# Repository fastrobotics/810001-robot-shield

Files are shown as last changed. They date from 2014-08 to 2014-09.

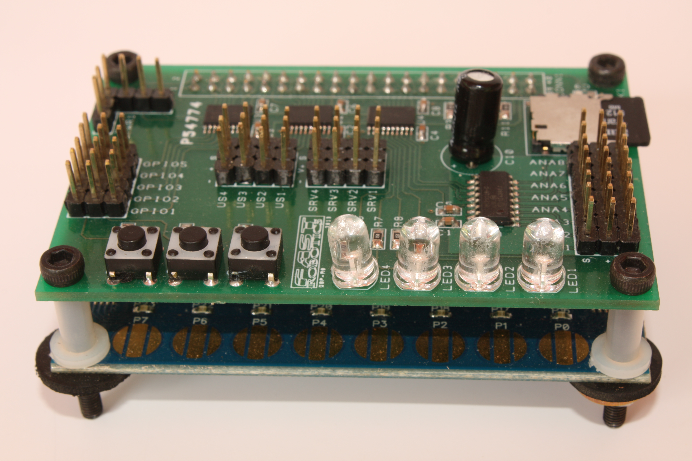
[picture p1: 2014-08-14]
MEDIA/810001A_Robot Shield ISO.JPG

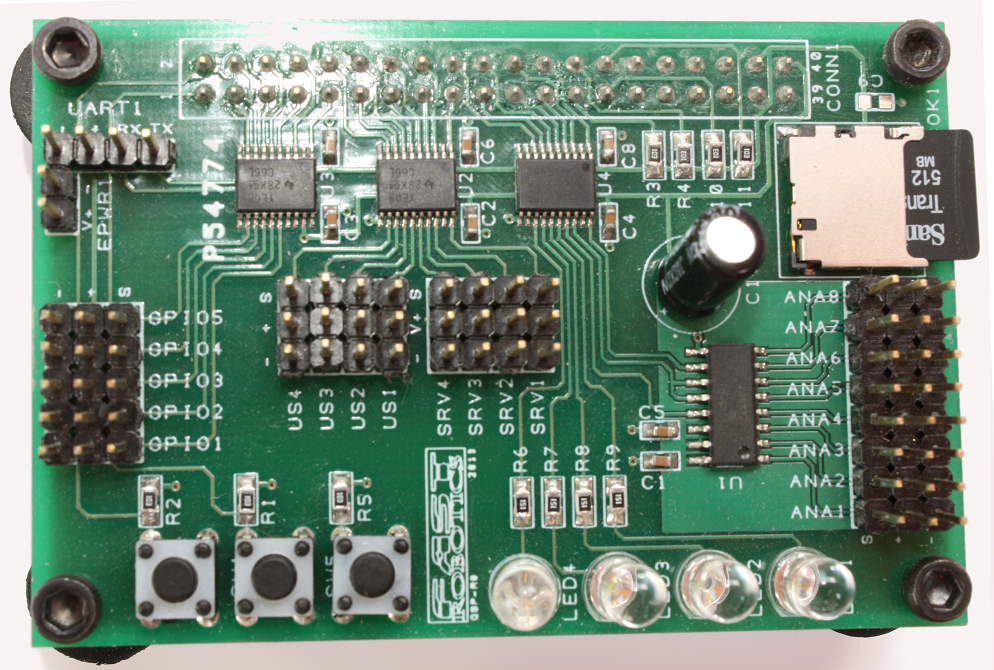
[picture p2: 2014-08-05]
MECH/810001_FAST Robot Shield/810001A/Top.png

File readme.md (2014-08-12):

810001 ROBOT SHIELD
===================
The Robot Shield is designed to connect to the Parallax Quickstart: http://www.parallax.com/product/40000

The Quickstart is a great board that included the Parallax Propeller, an 8-core microcontroller.  But there aren't a lot
of nice compact options to connect the Quickstart to a physical system, like your new pet robot.  That's where the 
Robot Shield comes in!  Here are some of its features:

* 5 GPIO Pins
* 8 Analog Inputs
* 4 Ultrasonic Input Pins (can also be used as GPIO).
* 4 Servo Outputs that are powered off an external power source.
* SD Card slot
* ... And More!

For a complete datasheet see: https://github.com/fastrobotics/810001_robot-shield/blob/master/810001_Robot%20Shield%20Datasheet.pdf

To get you started, we have provided a nice demo of hooking up a a Robot to the Quickstart and the Robot Shield and 
controlling by a laptop GUI.  A Hookup Guide is here:  https://github.com/fastrobotics/810001_robot-shield/blob/master/DOCUMENTATION/840005_FAST%20ROVER%2C%20QUICKSTART%2C%20ROBOT%20SHIELD%20HOOKUP%20GUIDE.pdf

And you can watch a video demonstrating this here:

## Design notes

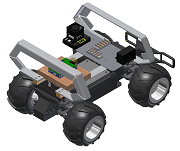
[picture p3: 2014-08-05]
SOFTWARE/646002_Rover GUI/646002A/Iso.png

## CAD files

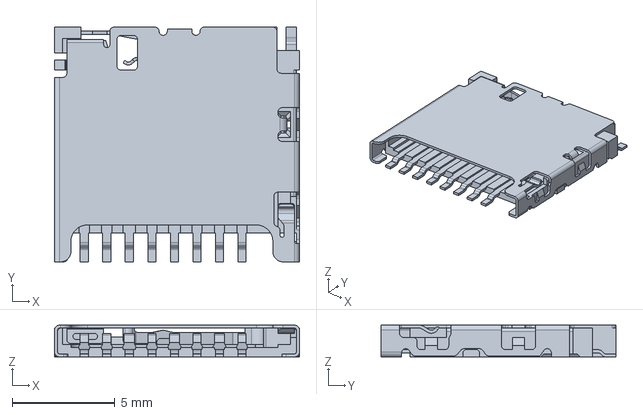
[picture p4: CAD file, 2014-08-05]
MECH/810001_FAST Robot Shield/810001A/DM3D-SF/DM3D-SF.stp
11.9 x 11.4 x 1.55 mm

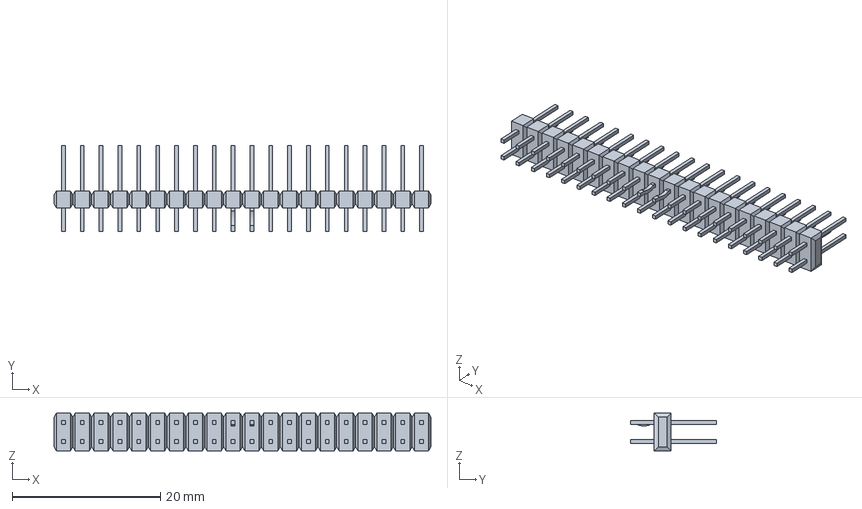
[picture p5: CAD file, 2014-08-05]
MECH/810001_FAST Robot Shield/810001A/70287-1018_stp/702871018.stp
50.8 x 11.6 x 5.08 mm

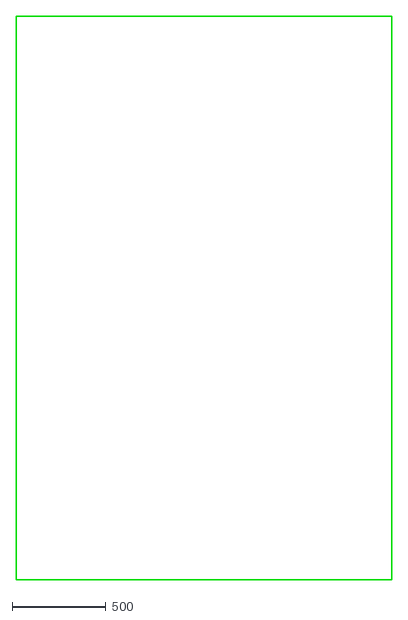
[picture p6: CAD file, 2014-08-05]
MECH/818000_Robot Shield PCB/818000A/818000A.dxf
2000.0 x 3000.0

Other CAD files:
MECH/840004_FAST ROVER, QUICKSTART, ROBOT SHIELD HOOKUP/840004A/840004_FAST ROVER, QUICKSTART, ROBOT SHIELD HOOKUP.dwg
MECH/810001_FAST Robot Shield/810001A/0805, RA-SM_24.ipt
MECH/810001_FAST Robot Shield/810001A/0805, RA-SM_242.ipt
MECH/810001_FAST Robot Shield/810001A/0805, RA-SM_244.ipt
MECH/810001_FAST Robot Shield/810001A/2, 2WP_12.ipt
MECH/810001_FAST Robot Shield/810001A/2, 2WP_122.ipt
MECH/810001_FAST Robot Shield/810001A/2, 2WP_124.ipt
MECH/810001_FAST Robot Shield/810001A/3, 3WP_3.ipt
MECH/810001_FAST Robot Shield/810001A/3, 3WP_32.ipt
MECH/810001_FAST Robot Shield/810001A/3, 3WP_34.ipt
MECH/810001_FAST Robot Shield/810001A/3MMH-40, 2540-6002_141.ipt
MECH/810001_FAST Robot Shield/810001A/4, 4WP_33.ipt
MECH/810001_FAST Robot Shield/810001A/4, 4WP_332.ipt
MECH/810001_FAST Robot Shield/810001A/4, 4WP_334.ipt
MECH/810001_FAST Robot Shield/810001A/810001-X0.iam
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

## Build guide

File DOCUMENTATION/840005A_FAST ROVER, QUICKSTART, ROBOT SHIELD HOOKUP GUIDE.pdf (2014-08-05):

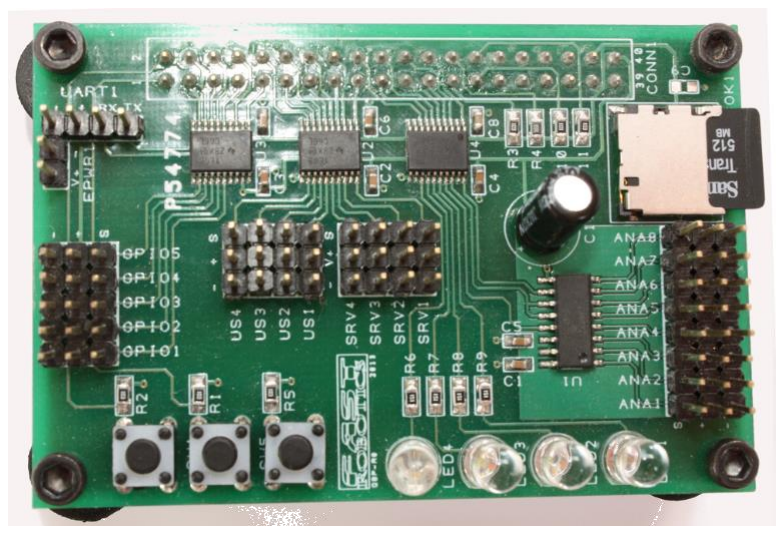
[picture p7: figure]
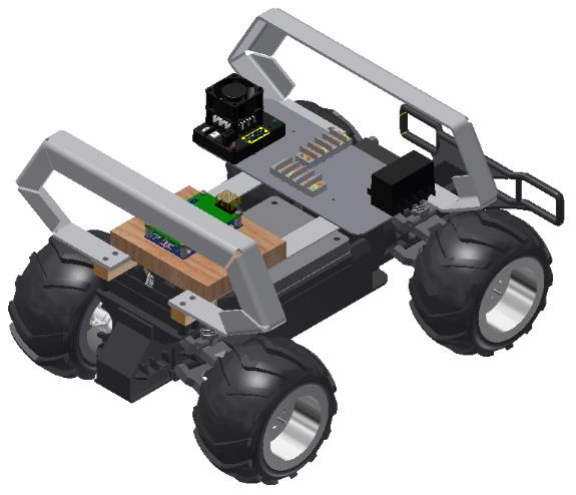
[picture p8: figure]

Copyright © FAST Robotics | 810001 Robot Shield | Rev A 8/5/2014 | 1 | P a g e

www.fast-robotics.com
info@fast-robotics.com
https://github.com/fastrobotics

## Robot Shield (#810001) Hookup Guide

Key Features
- 8 Analog Inputs
- 9 GPIO
- 4 LED’s
- MicroSD Card Slot
- 2 User Switches
- UART Interface (FTDI compatible)
- Reset Switch
- 5V Power Input
- Servo Power Input

Overview
To provide a good example of how to use the FAST Robotics Robot Shield, we have created a Demo Robot that uses the Robot Shield along with a Parallax Quickstart on a 4 wheel drive Robot Chassis driven by one DC motor and one steering servo. The Rover is a slightly modified Radioshack Hummer H2 60-195 (Discontinued). The main modification to the Rover was removing the OEM steering motor and installing a Futaba High-Torque Servo, along with installing some better mounting points to the chassis.

NOTE: For this Guide, we are not providing instructions to use a wireless option. The FAST Robotics Robot Shield is completely compatible with most serial Radio products, we are just saving that guide for our next project, the Radio Shield! As such, please ensure that when you are driving your most fearsome robot around that the USB cable you have connected to it doesn’t interfere with the wheels, robot suspension, pets, feral animals, small children, etc.

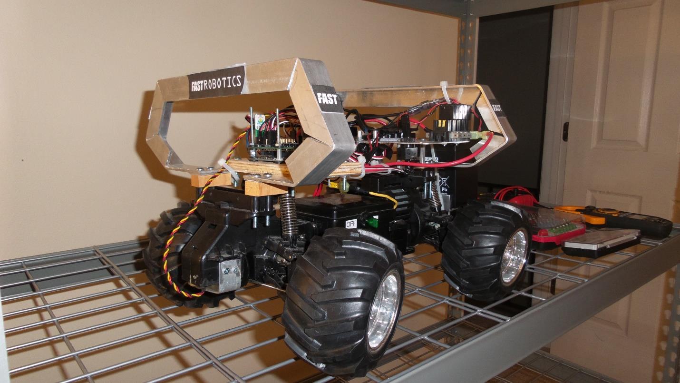
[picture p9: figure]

Copyright © FAST Robotics | 810001 Robot Shield | Rev A 8/5/2014 | 2 | P a g e

Components Required
1. Rover Chassis w/ 1 DC Motor and 1 Servo
2. Parallax Quickstart (#811000)
3. FAST Robotics Robot Shield (#810001)
4. Shield Hardware Kit (#810501)
5. IFI Victor 884 Speed Controller
6. Parallax Prop-Plug
7. 6V 5A DC-DC Regulator
8. 5V 5A DC-DC Regulator
9. 2x Toggle Switches
10. 1 USB to USB-Mini Cable
11. Assorted Power and PWM Cables

Software Required
1. Parallax Propeller Tool (http://www.parallax.com/downloads/propeller-tool-software)
2. Robot Shield Demo (https://github.com/fastrobotics/810001_robot-shield/tree/master/SOFTWARE/646003_Robot%20Shield%20Demo/646003A)
3. Rover GUI (https://github.com/fastrobotics/810001_robot-shield/tree/master/SOFTWARE/646002_Rover%20GUI/646002A)

Documents Required
1. Robot Shield Datasheet (https://github.com/fastrobotics/810001_robot-shield/blob/master/810001_Robot%20Shield%20Datasheet.pdf)
2. Hookup Diagram – Power (https://github.com/fastrobotics/810001_robot-shield/blob/master/DOCUMENTATION/840004_FAST%20ROVER%2C%20QUICKSTART%2C%20ROBOT%20SHIELD%20HOOKUP%20DIAGRAM%20-%2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) and Data (https://github.com/fastrobotics/810001_robot-shield/blob/master/DOCUMENTATION/840004_FAST%20ROVER%2C%20QUICKSTART%2C%20ROBOT%20SHIELD%20HOOKUP%20DIAGRAM%20-%2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)
3. Robot Shield Schematic (https://github.com/fastrobotics/810001_robot-shield/blob/master/ELEC/810001A/SCH-810001A.pdf)

Install Components & Connections
After installing all components, wire them according to the Power and Data Diagrams.

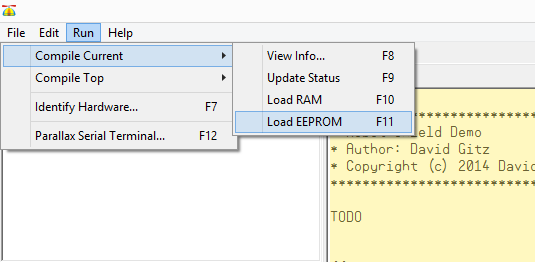
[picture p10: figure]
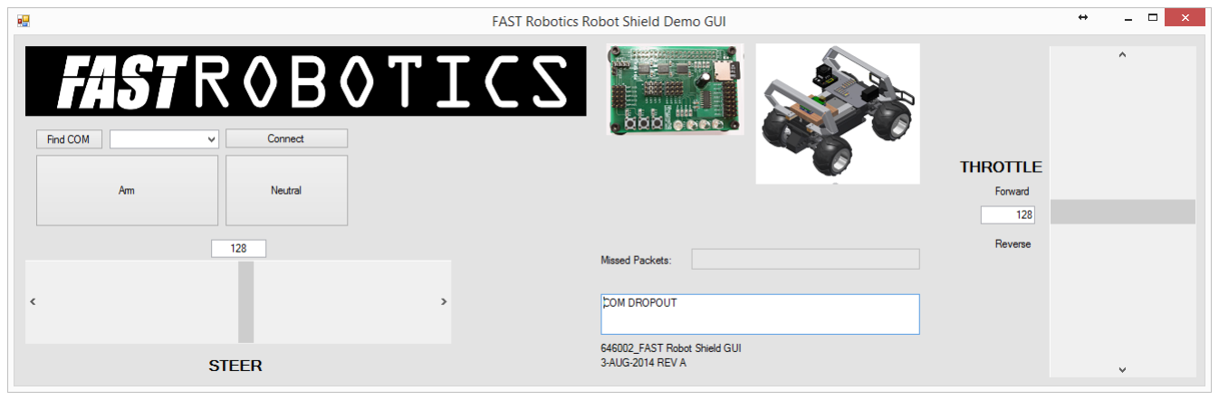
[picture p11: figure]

Copyright © FAST Robotics | 810001 Robot Shield | Rev A 8/5/2014 | 3 | P a g e

For any Digital Inputs to the Robot Shield you will need a Pull-Up Resistor. All 12V, 5V and 6V wires use 12AWG stranded wire.

After wiring all the components it’s time to program the Quickstart. After installing the Parallax Propeller Tool download the Robot Shield Demo code, unzip it, open the Main.spin file in the Propeller Tool program and click “Run”->”Compile Current”->”Load EEPROM”.

Now find the Rover GUI executable “FAST Rover GUI.exe” and run it.

Now all you have to do is connect your USB cable to the Prop-Plug and connect that to UART1 on the Robot Shield. Turn on power and hit “Find COM”, then click Connect.

You will need to turn on the Arm Switch on the Robot and then you can hit the Arm button in the GUI. Now move the STEER and THROTTLE sliders around and your beast should move!

Further Steps
So what’s next? You could add an ultrasonic sensor on a pan servo for autonomous movement. Or you could add a robot arm and help pick up trash in your neighborhood.

Copyright © FAST Robotics | 810001 Robot Shield | Rev A 8/5/2014 | 4 | P a g e

You could even just drive the robot around your dog until she gets tired of chasing it. The choice is yours!

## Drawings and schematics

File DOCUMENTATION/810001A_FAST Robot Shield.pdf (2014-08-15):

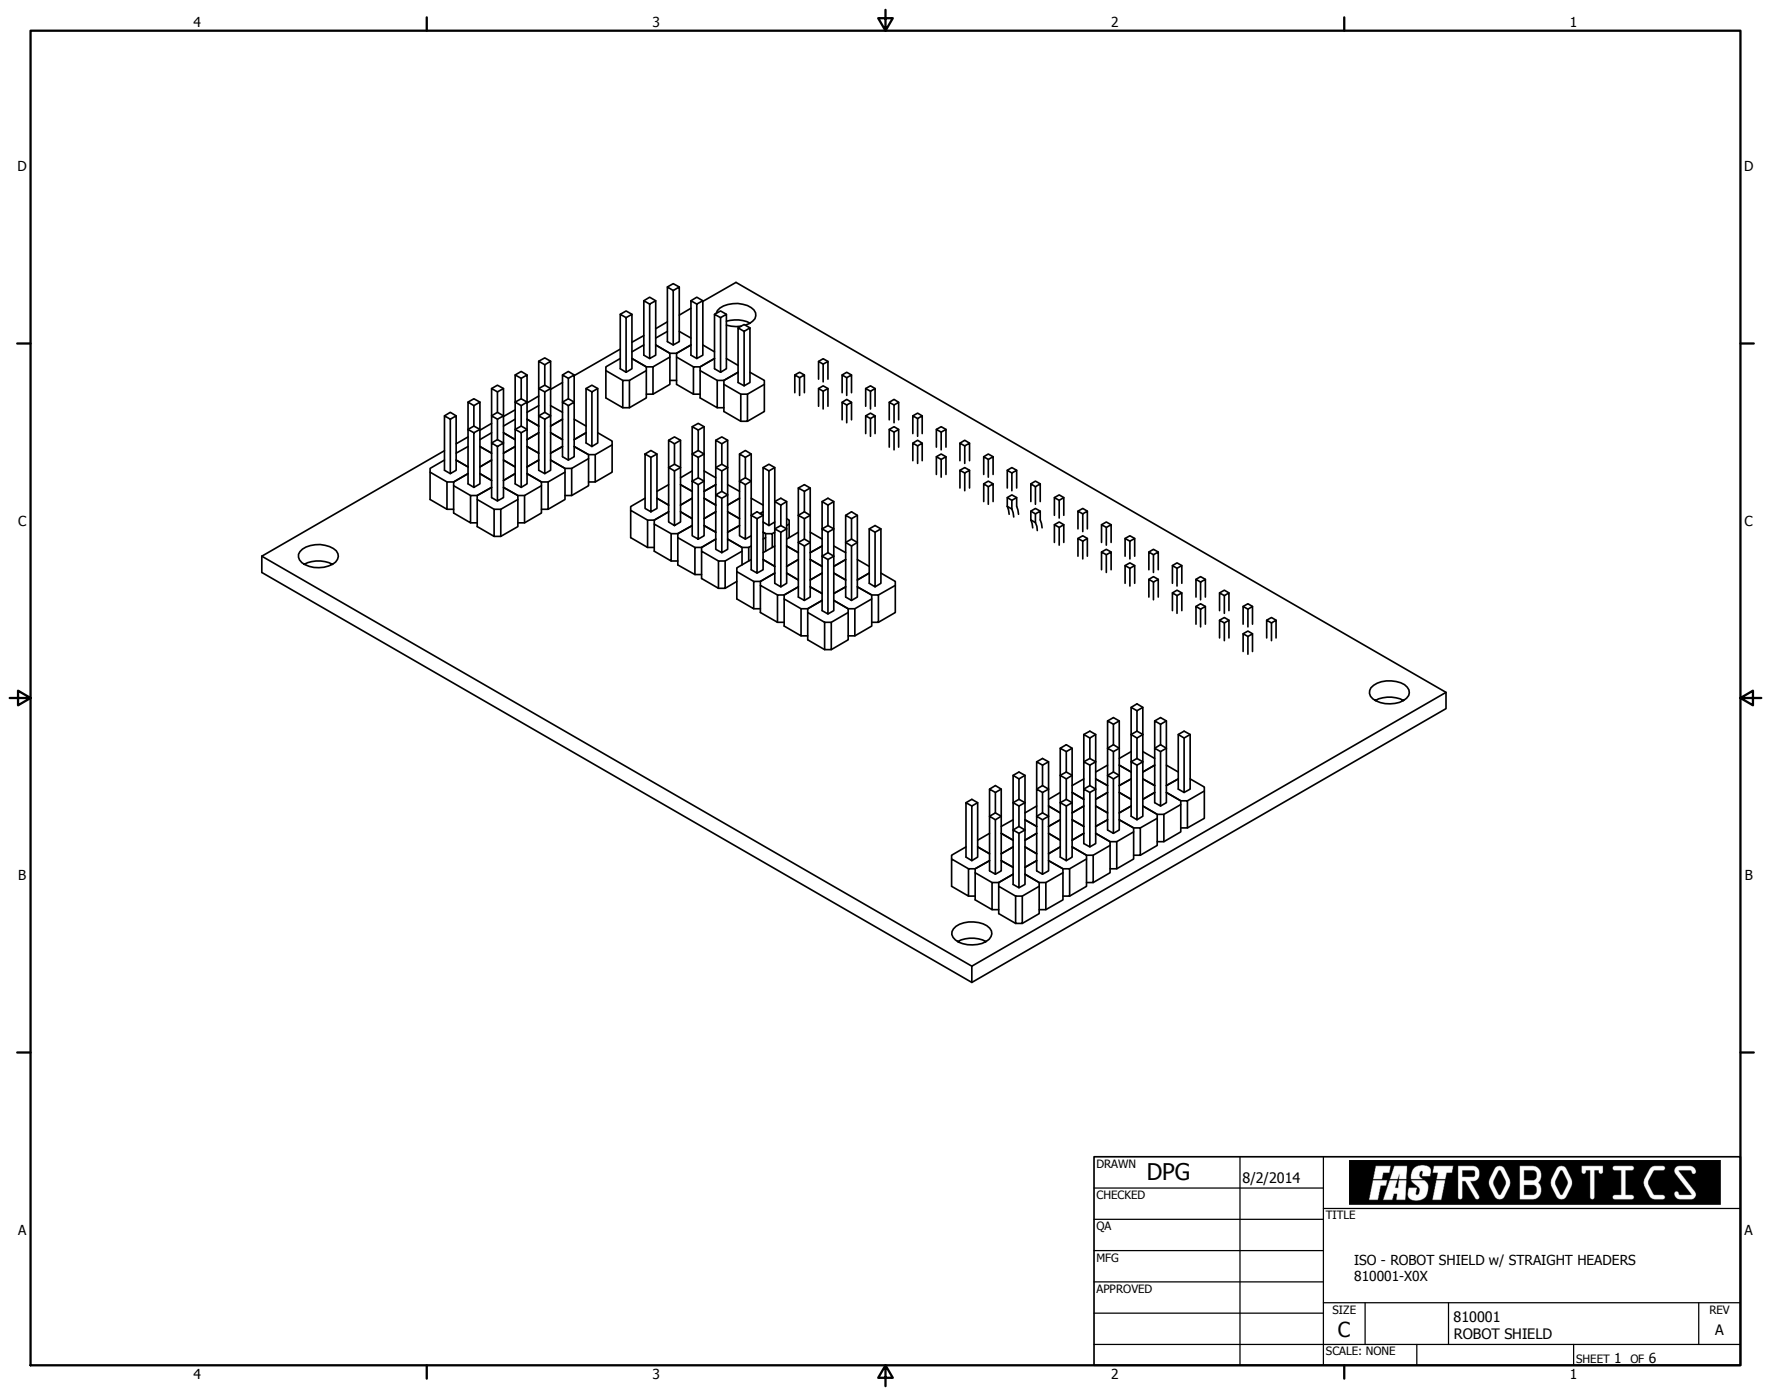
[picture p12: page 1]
SHEET 1 OF 6; DRAWN; CHECKED; MFG; APPROVED; TITLE; SIZE C; SCALE: NONE; REV A; DPG; ROBOT SHIELD

ISO - ROBOT SHIELD w/ STRAIGHT HEADERS

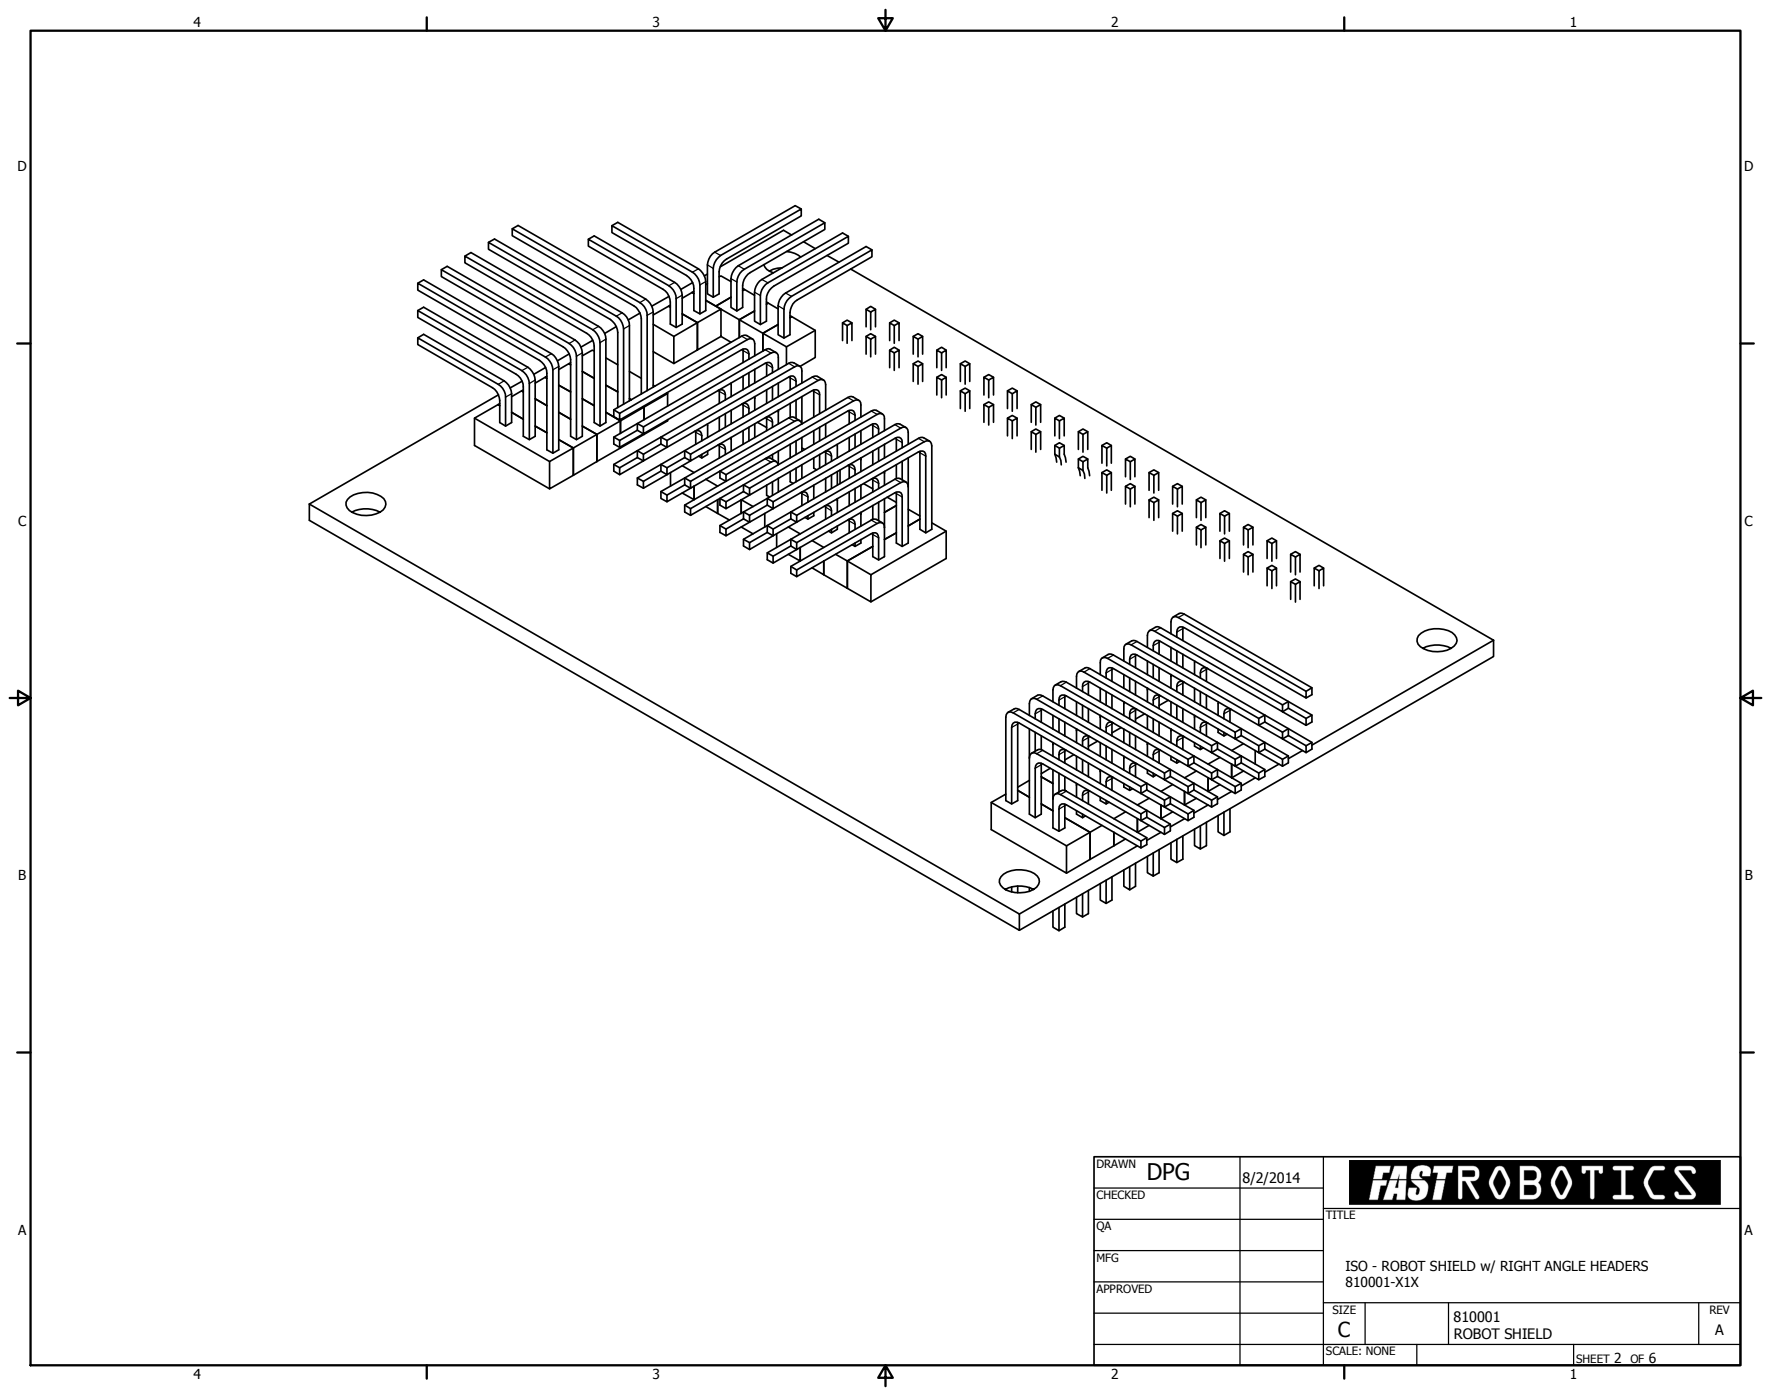
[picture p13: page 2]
DRAWN; CHECKED; MFG; TITLE; DPG

ISO - ROBOT SHIELD w/ RIGHT ANGLE HEADERS

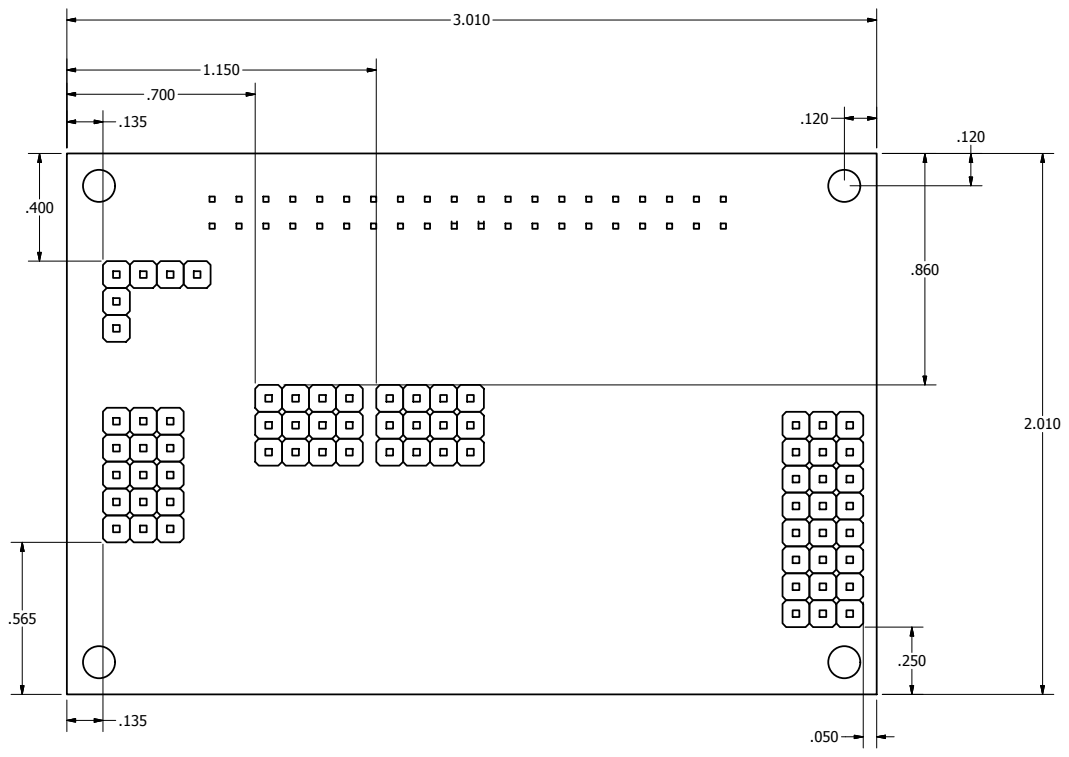
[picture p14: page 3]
DRAWN; CHECKED; MFG; TITLE; DPG

DIM - ROBOT SHIELD w/ STRAIGHT HEADERS

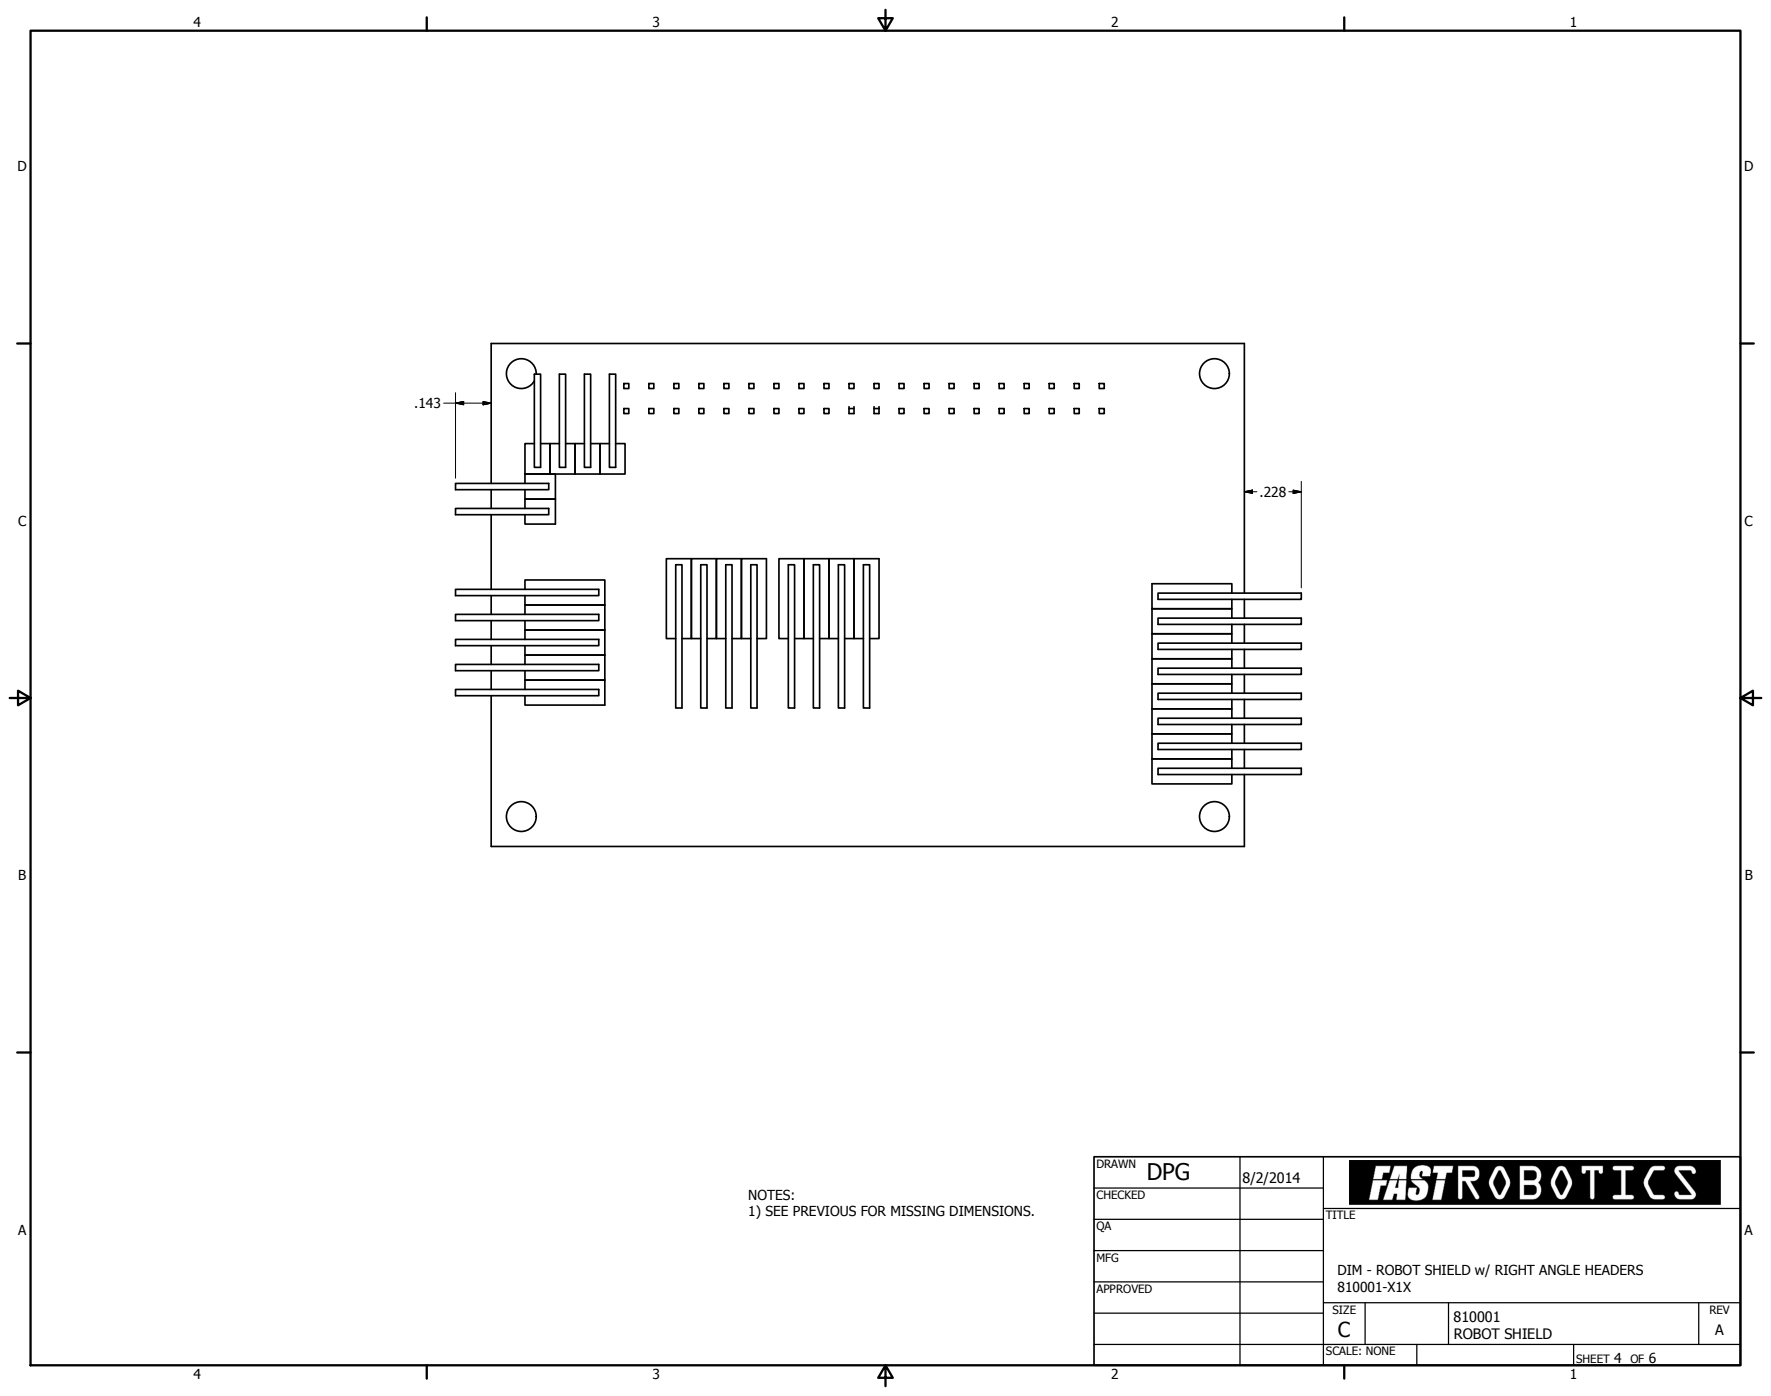
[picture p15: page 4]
DRAWN; CHECKED; MFG; TITLE; DPG

NOTES:
1) SEE PREVIOUS FOR MISSING DIMENSIONS.

DIM - ROBOT SHIELD w/ RIGHT ANGLE HEADERS

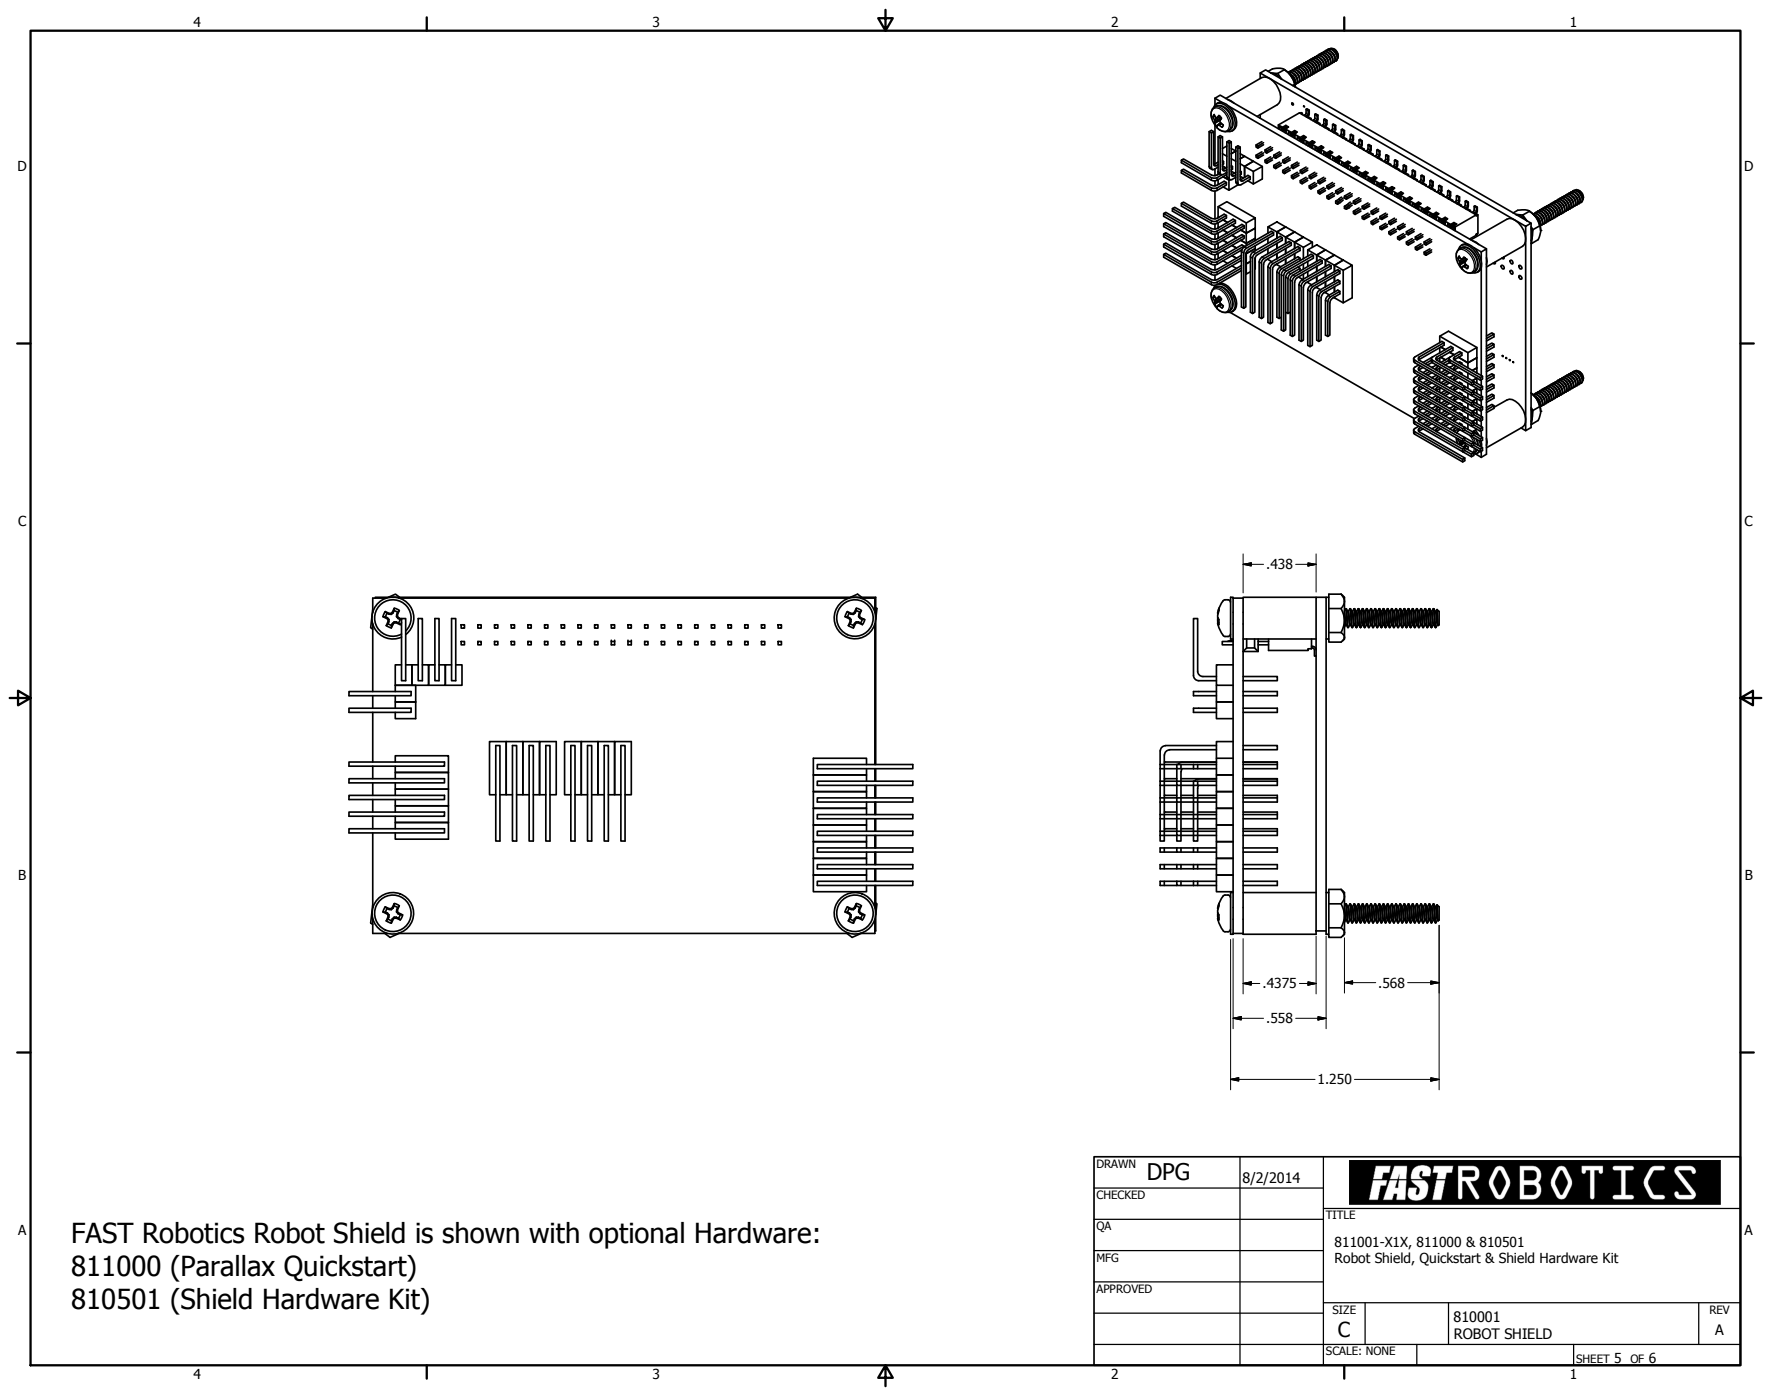
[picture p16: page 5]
DRAWN; CHECKED; MFG; TITLE; DPG

FAST Robotics Robot Shield is shown with optional Hardware:
811000 (Parallax Quickstart)
810501 (Shield Hardware Kit)

Robot Shield, Quickstart & Shield Hardware Kit

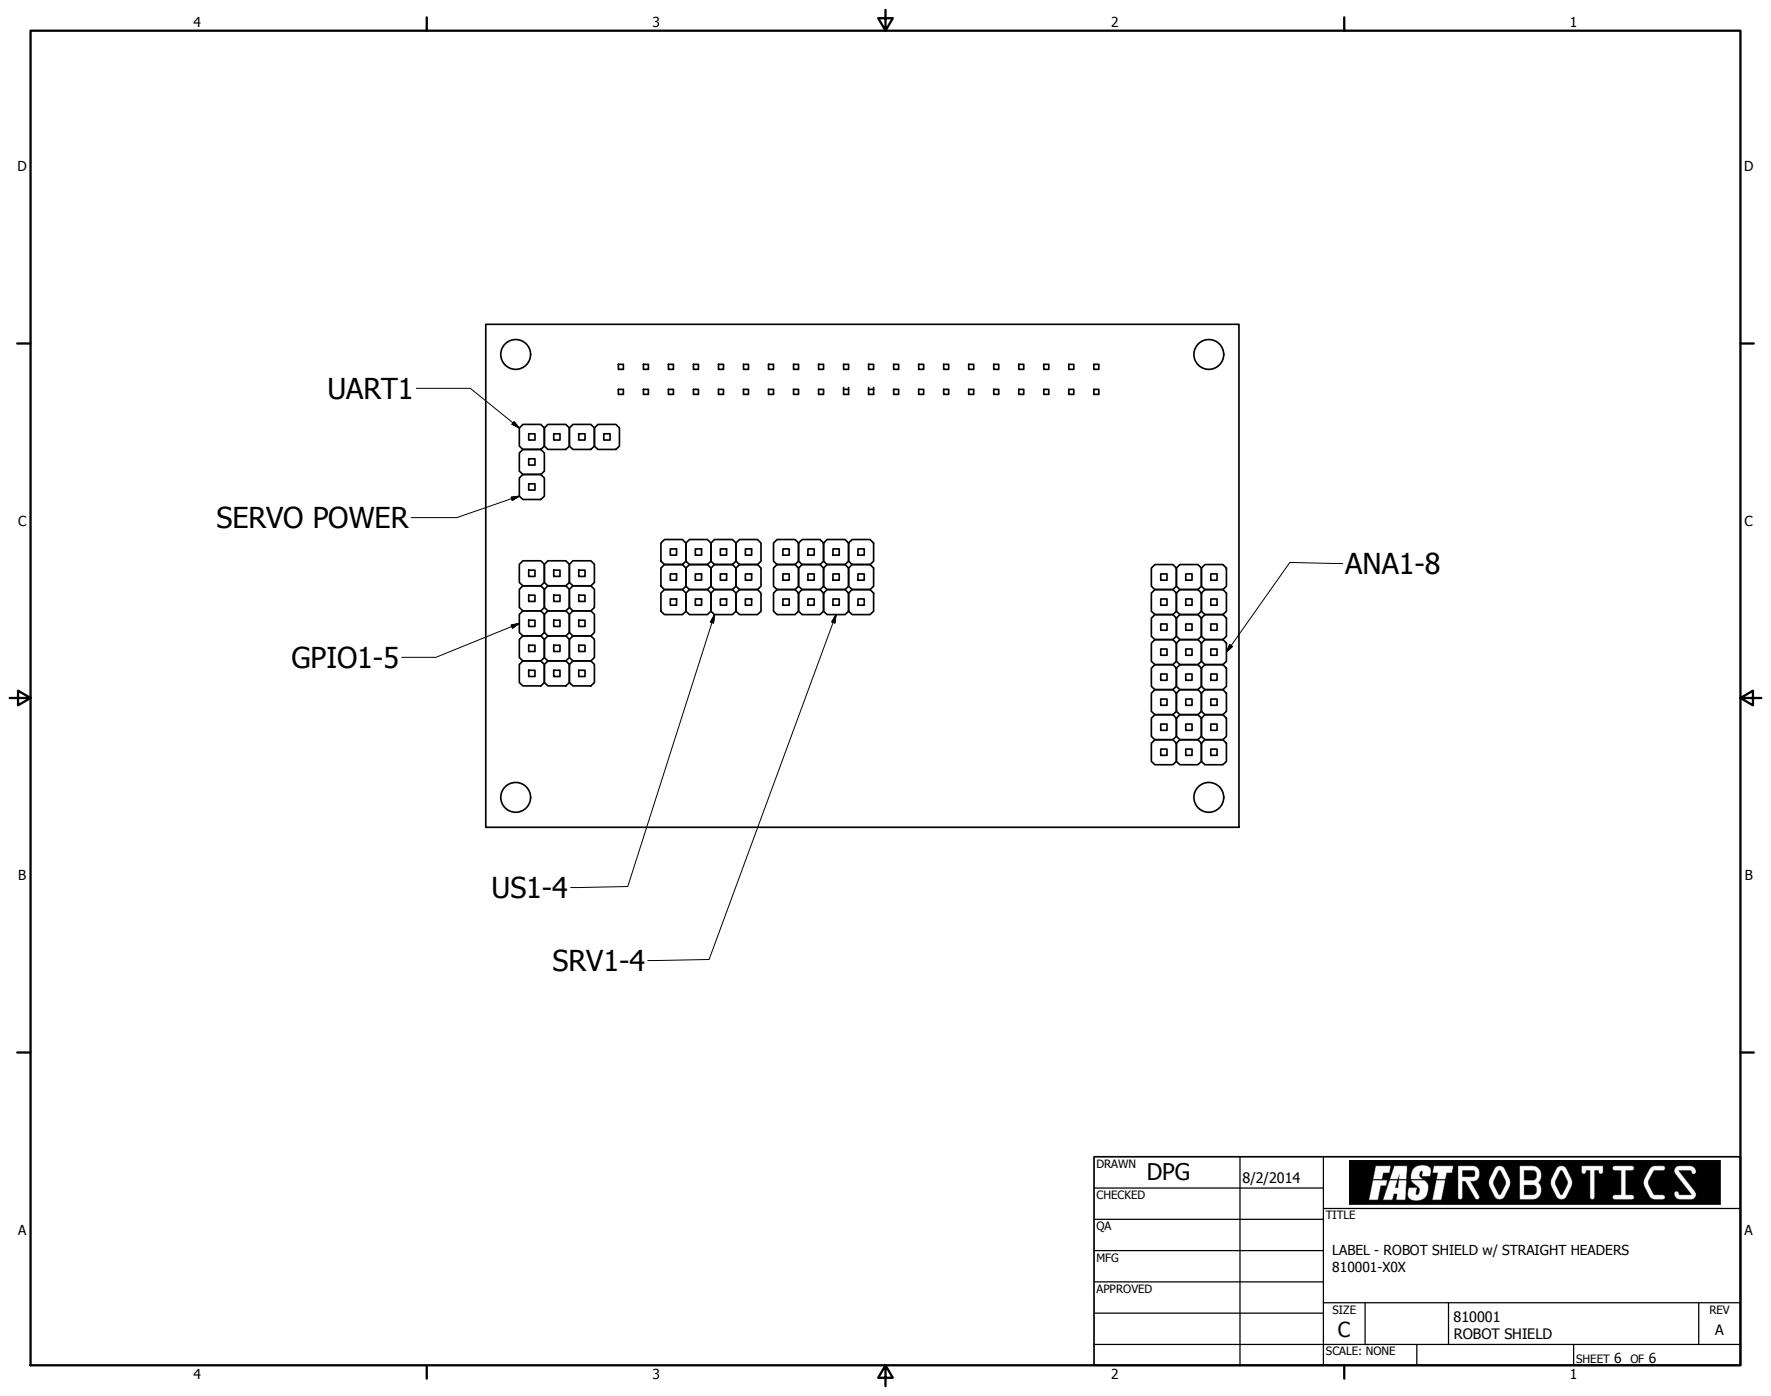
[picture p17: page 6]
DRAWN; CHECKED; MFG; TITLE; DPG; GPIO1-5; SERVO POWER; UART1; SRV1-4; ANA1-8

LABEL - ROBOT SHIELD w/ STRAIGHT HEADERS

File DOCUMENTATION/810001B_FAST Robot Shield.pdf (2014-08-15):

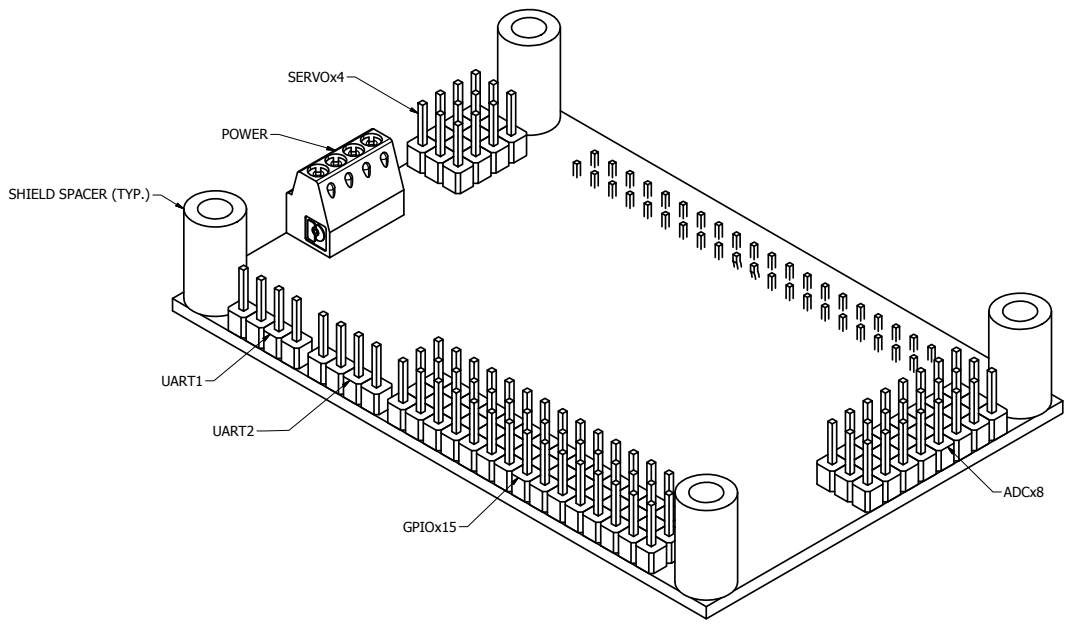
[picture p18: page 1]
SHEET 1 OF 2; DRAWN; CHECKED; MFG; APPROVED; TITLE; SIZE C; SCALE: NONE; REV; DPG; ROBOT SHIELD; SERVOx4; POWER; UART1; UART2; GPIOx15; ADCx8

SHIELD SPACER (TYP.)

ISO - ROBOT SHIELD w/ STRAIGHT HEADERS

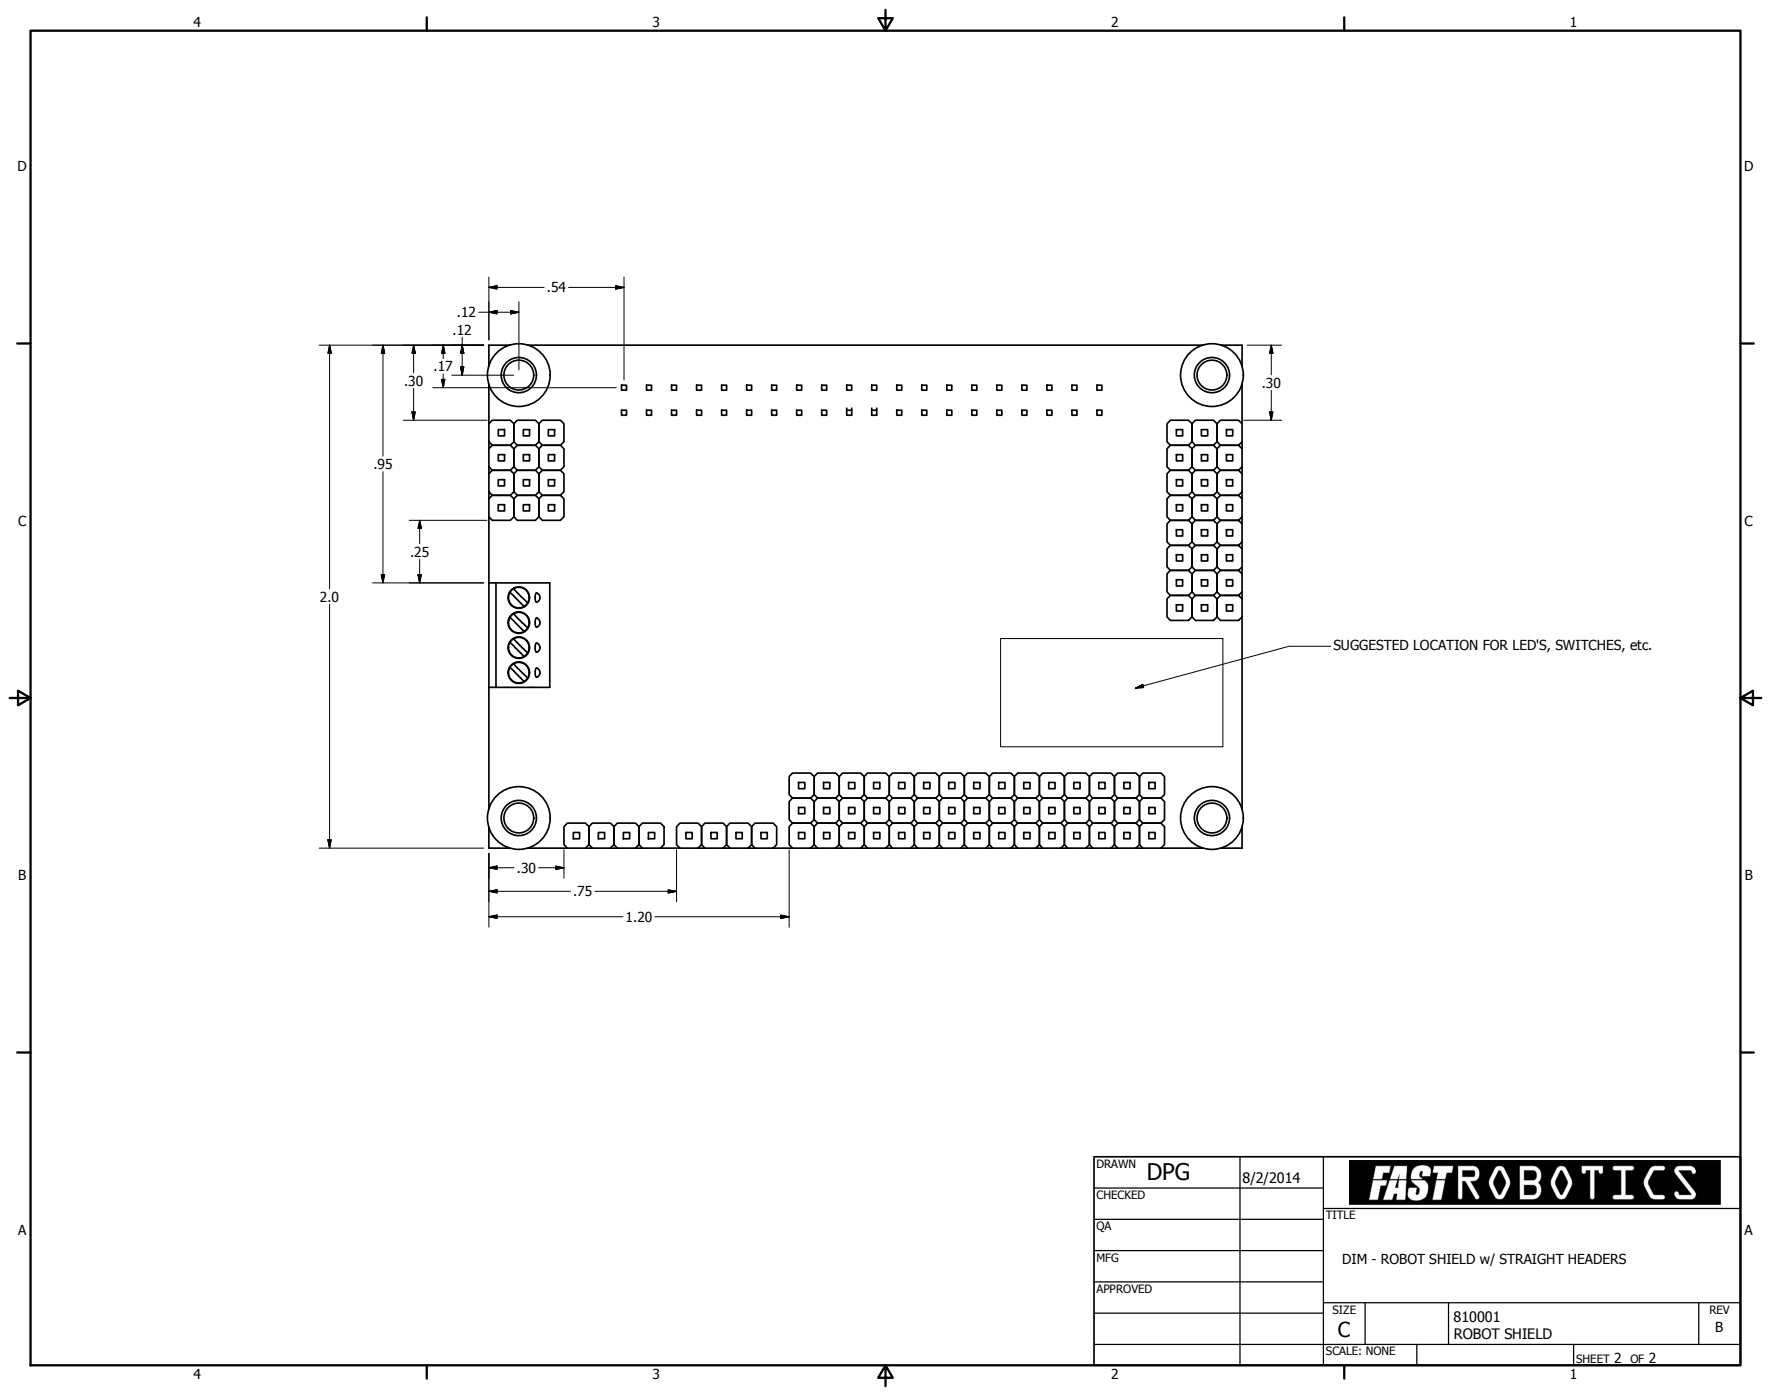
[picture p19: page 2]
SHEET 2 OF 2; DRAWN; CHECKED; MFG; APPROVED; TITLE; SIZE C; SCALE: NONE; REV; DPG; 810001 ROBOT SHIELD

SUGGESTED LOCATION FOR LED'S, SWITCHES, etc.

DIM - ROBOT SHIELD w/ STRAIGHT HEADERS

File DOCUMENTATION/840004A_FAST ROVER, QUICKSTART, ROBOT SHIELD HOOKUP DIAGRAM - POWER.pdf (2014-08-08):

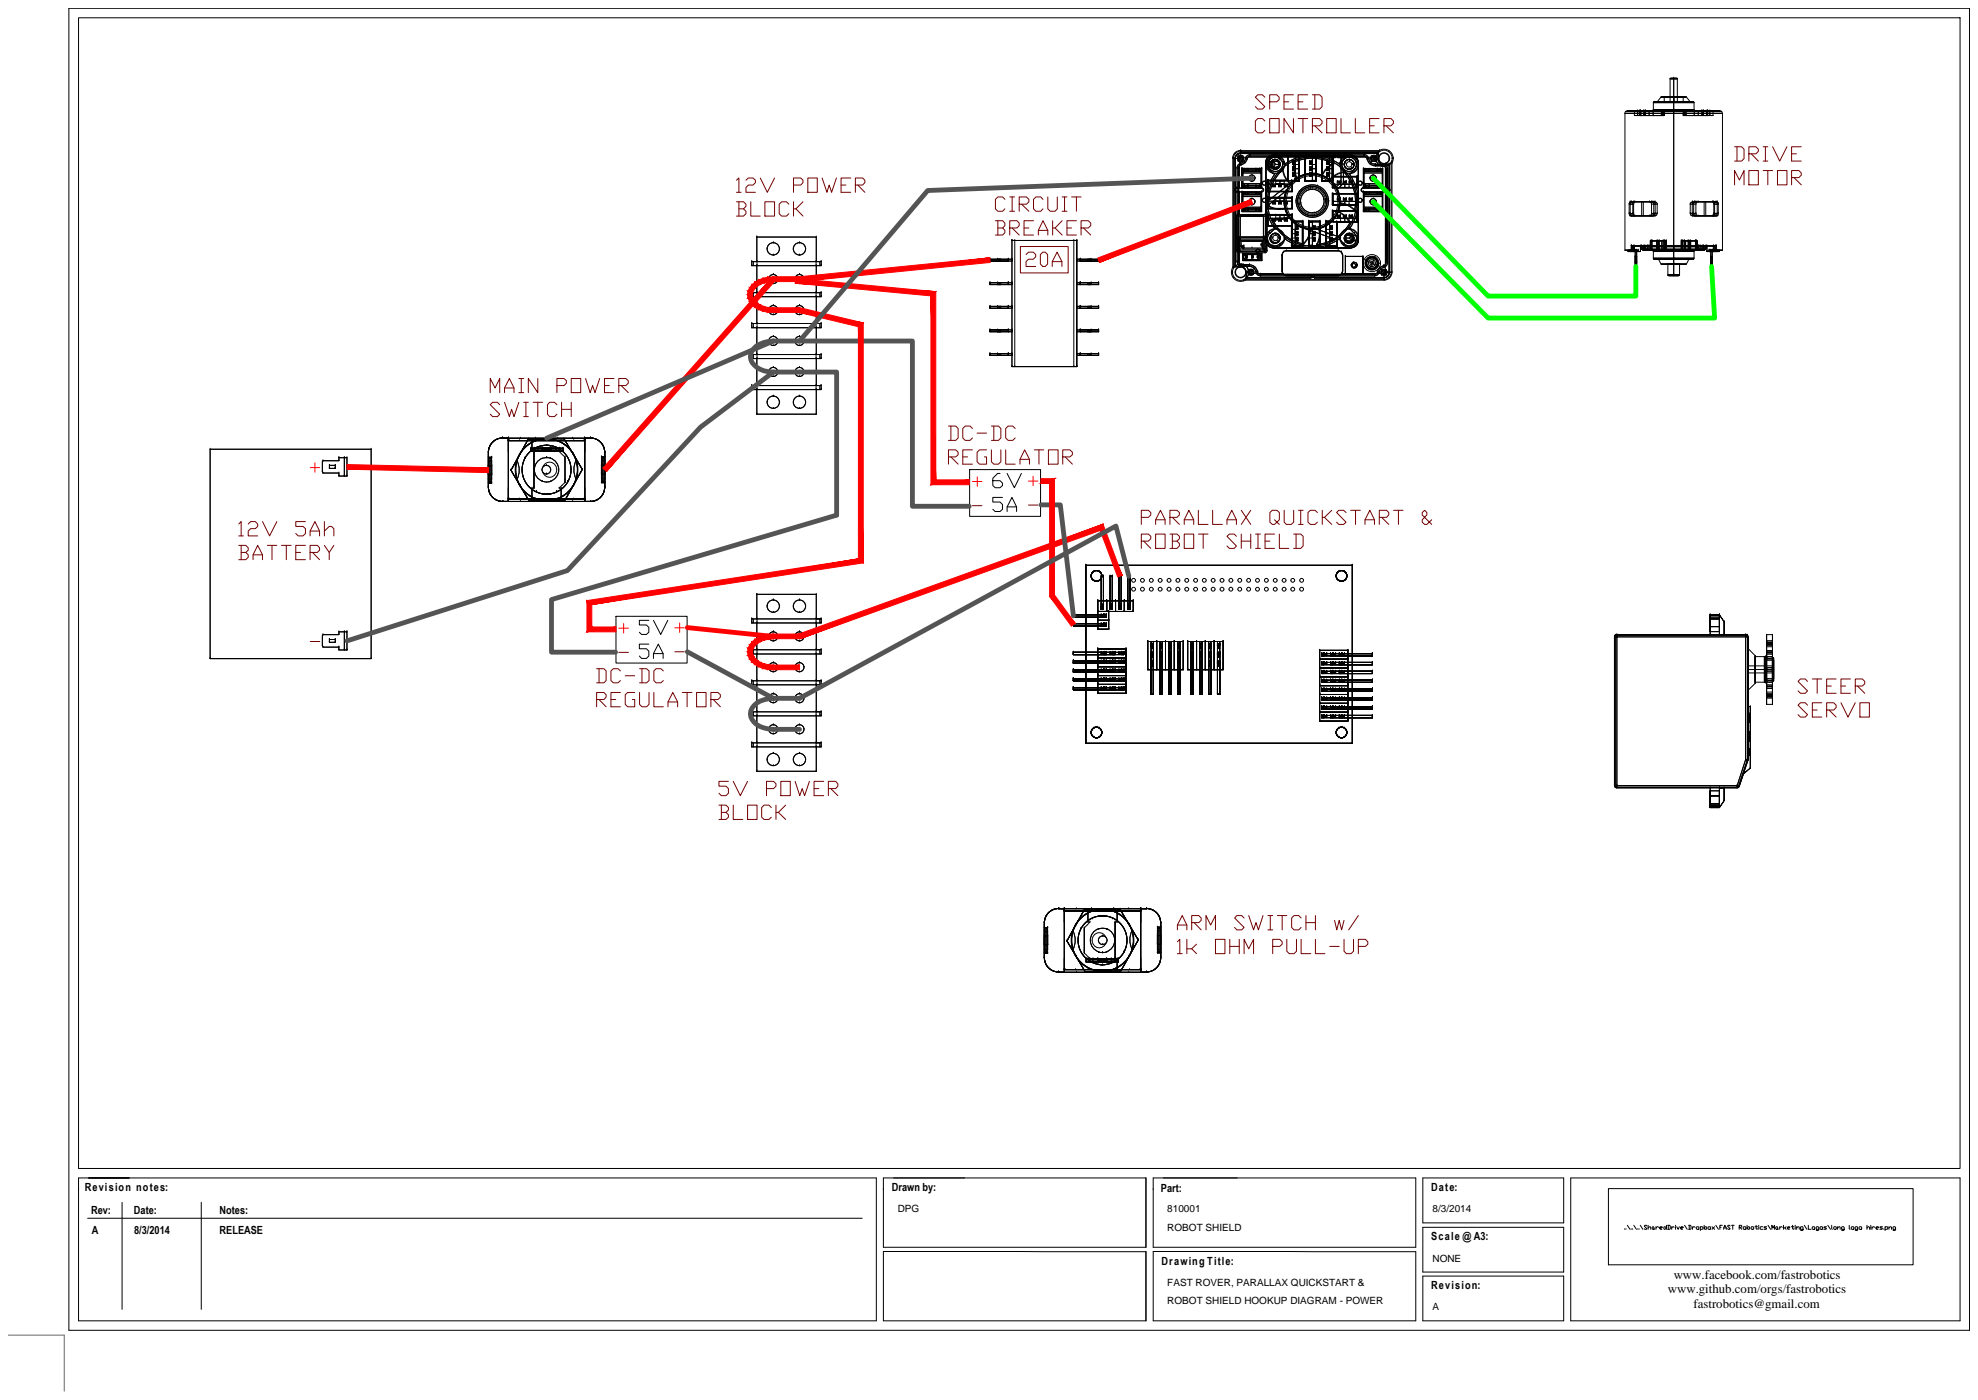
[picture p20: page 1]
Revision: Part:; Revision notes: Rev:; Date:; Notes:; www.facebook.com/fastrobotics www.github.com/orgs/fastrobotics; Drawn by: DPG; 810001 ROBOT SHIELD FAST ROVER, PARALLAX QUICKSTART & ROBOT SHIELD HOOKUP DIAGRAM - POWER; 8/3/2014 NONE

Scale @ A3: Drawing Title:

fastrobotics@gmail.com

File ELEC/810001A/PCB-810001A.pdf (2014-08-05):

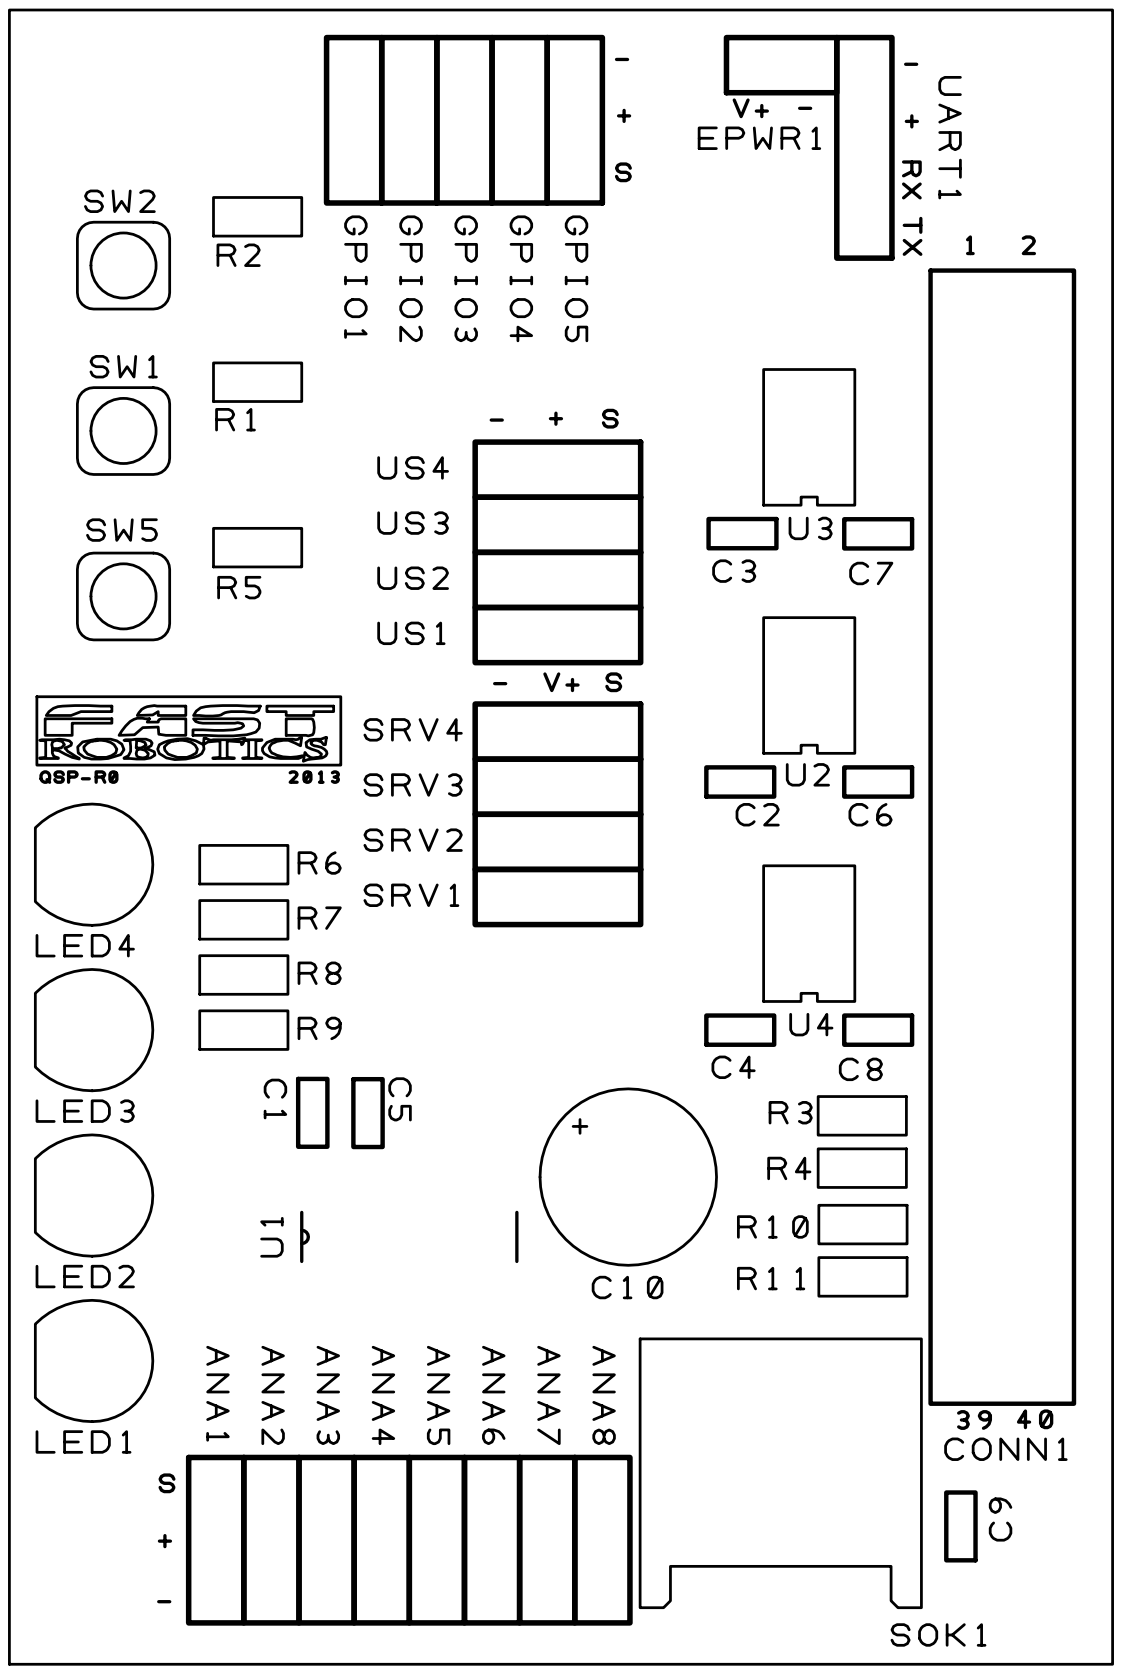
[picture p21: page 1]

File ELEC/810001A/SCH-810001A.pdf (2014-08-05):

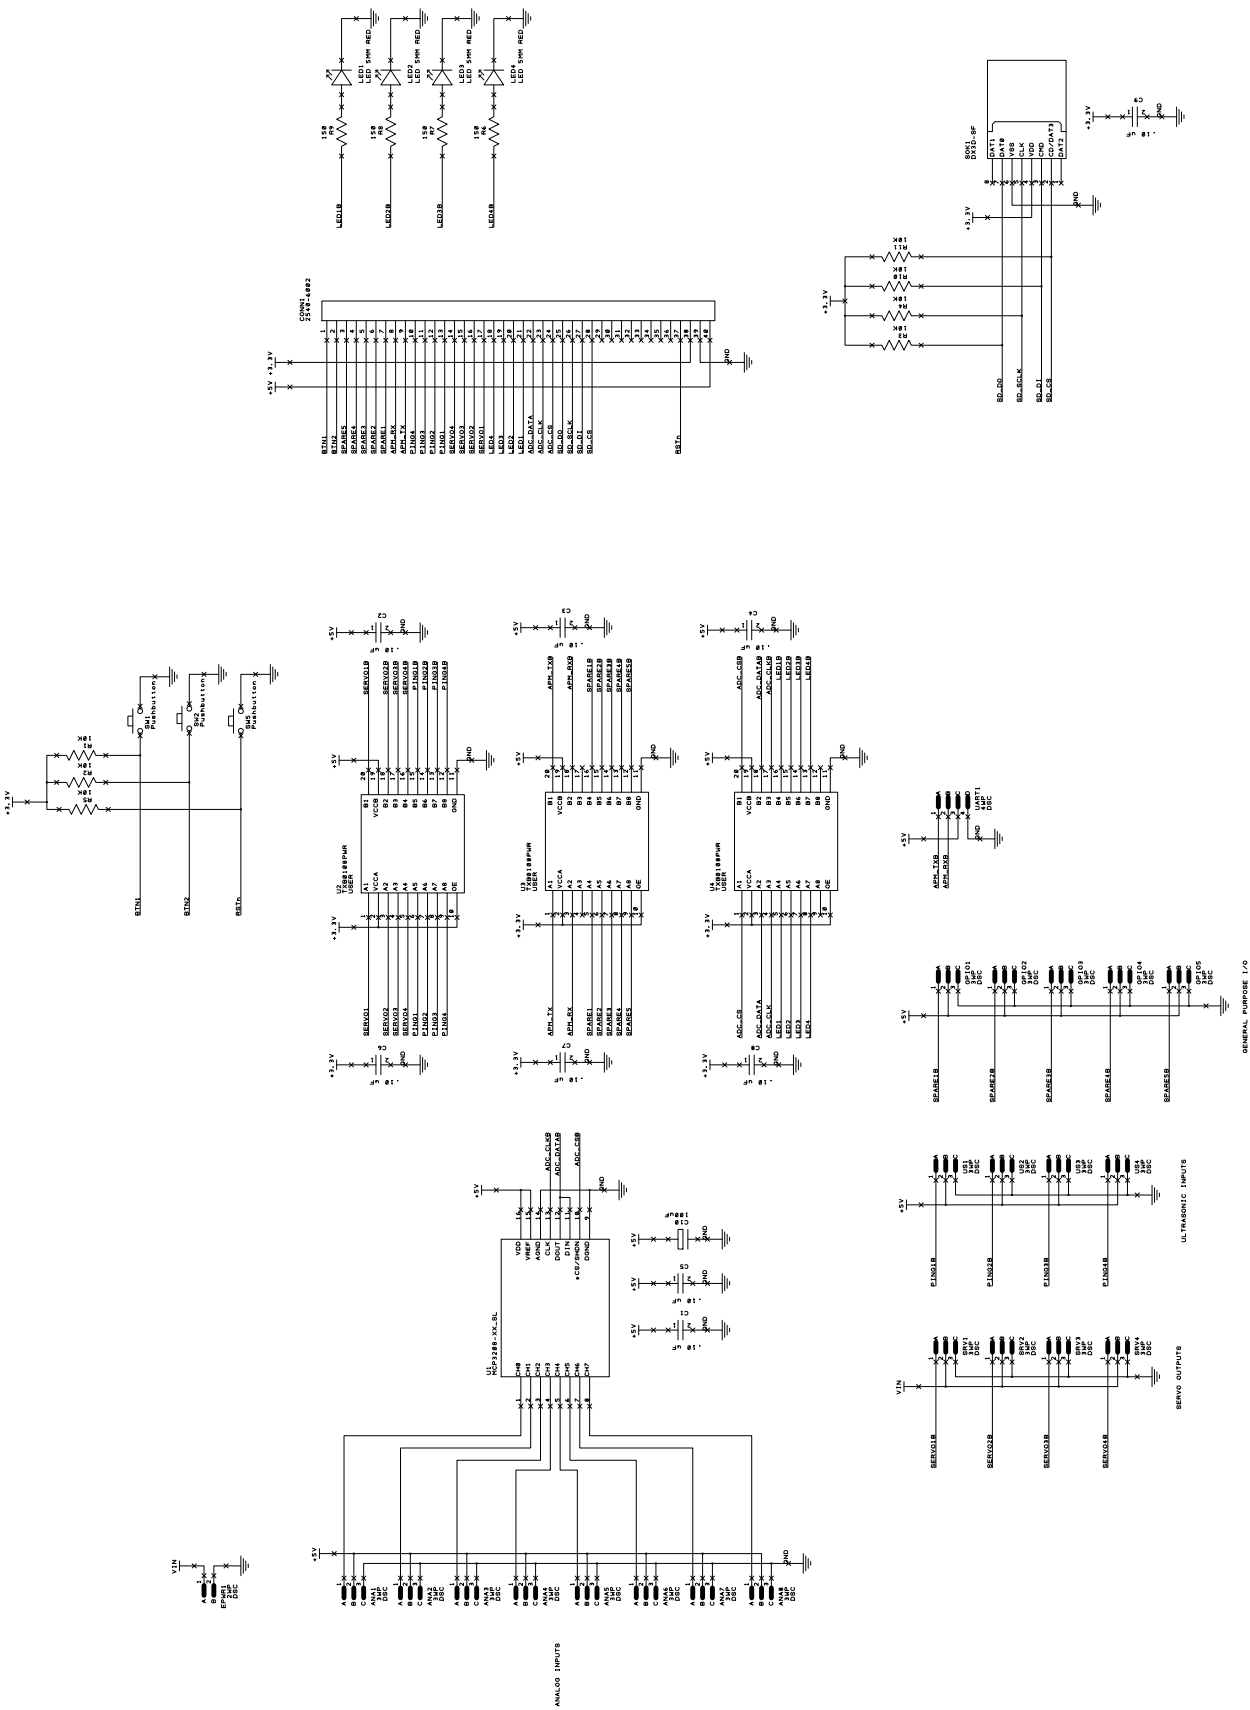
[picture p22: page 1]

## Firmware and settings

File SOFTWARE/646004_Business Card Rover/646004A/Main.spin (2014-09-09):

{{               
********************************************************
* Marketing Rover                                      *
* Author: David Gitz                                   *
* Copyright (c) 2014 David Gitz/FAST Robotics          *     
********************************************************

TODO
 - 
   
{{
TARGET:
  - Parallax Quickstart and Robot Shield (FR# 810001)
PURPOSE:
  - 
}}
{{
SETUP:
}}
{{
INDICATOR LIGHTS
LED1: On During Startup, Off otherwise
LED2: Blinking if Running, On in CLI Mode, Off if Not Running
LED4: On if Error, Off otherwise.
}}
{{
LOG:
  DPG 30-AUG-2014.  Created Program.  
 
  
}}
CON

' Timing             
  _clkmode = xtal1 + pll16x
  _xinfreq = 5_000_000 
  
' ASCII Constants
  CR = 13
  LF = 10
  SPACE = 32
  PERIOD = 46
  COMMA =  44
  TAB = 9

 'Loop Rates
  FAST_LOOP = 1 '100 Hz, 10 mS
  MEDIUM_LOOP = 10 '10 Hz, 50 mS
  SLOW_LOOP = 100 '1 Hz, 200 mS

  PRIORITY_HIGH = 0
  PRIORITY_MEDIUM = 1
  PRIORITY_LOW = 2  

  ' UART Definitions
    debug_port = 0
    com_port = 1
      
  ' Hardware Pins************************************
  PINNOTUSED = -1                    

  ' UART Pins
  usbtx = 30  'USB TX Line
  usbrx = 31  'USB RX Line
  comtx = 8  'Robot Shield TX Line, FIX
  comrx = 7  'Robot Shield RX Line, FIX

' Led's

  LED4 = 17
  LED3 = 18
  LED2 = 19
  LED1 = 20

' Motor Out Pin: Set to -1 if not used
  SERVO1 = 16
  SERVO2 = 15
  SERVO3 = 14
  SERVO4 = 13

  'ADC Pins/Misc
  ADCuartPin = 21
  ADCclkPin = 22
  ADCcsPin = 23


  'Analog Sensors
  AnalogSense1 = 0
  AnalogSense2 = 1
  AnalogSense3 = 2
  AnalogSense4 = 3
  AnalogSense5 = 4
  AnalogSense6 = 5
  AnalogSense7 = 6
  AnalogSense8 = 7

 'GPIO Pin Definitions
  GPIO1 = 6
  GPIO2 = 5
  GPIO3 = 4
  GPIO4 = 3
  GPIO5 = 2

  'US Pin Definitions.  These are just more GPIO
  US1 = 13
  US2 = 12
  US3 = 11
  US4 = 10

  'SD Card Pin Definitions
  SD_DO = 24
  SD_SCLK = 25
  SD_DI = 26
  SD_CS = 27

' ****************************************************  

  'ADC Definitions
  ADC_VOLTAGE_CONVERSION = 18   
  ADC_LOWER_THRESHOLD = 100  'Threshold for converting Analog Input to Boolean states.  Below this is FALSE.
  ADC_UPPER_THRESHOLD = 3900   'Threshold for converting Analog Input to Boolean states.  Above this is TRUE.
  ADC_MIN_VALUE = 0
  ADC_MAX_VALUE = 4096
  ADCmode = $00FF  
  
 'PWM/Motor Definitions

  PWM_MIN_VALUE = 1000
  PWM_MAX_VALUE = 2000
  PWM_NEUTRAL_VALUE = 1500 


  'FAST Protocol Definitions
  SD = $24
  ED = $2A
  'Message/Sub-Message Type Definitions
  MT_ERROR = $01
  SMT_NOERROR = $01


  'Value Type Definitions
  VT_NODATA = $FF
  VT_1INT = $01
   
  ' User Pin Definitions
  Arm_Pin = GPIO1
  Startup_LED = LED1
  Run_LED = LED2
  Armed_LED = LED3
  Error_LED = LED4

  'Ultrasonic Sensor Definitions
  PING_FRONT = GPIO1
  PING_LEFT = GPIO2
  PING_RIGHT = GPIO3
  

  'Obstacle Detecion/Avoidance Stuff
  BEYONDFAR = 100
  FAR = 60
  MID = 10
  GRIDSIZE = 7


OBJ
  uart:         "pcFullDuplexSerial4FC"
  pwmout:       "PWM_32_v4"
  util:         "Util"
  adc:          "MCP3208"
  timer:        "Timer"
  str:          "STRINGS2"
  sdcard:           "fsrw"
  ping:         "ping"
  math:         "spin_trigpack"

VAR
  'Program Variables
  byte cogsused

  'Timing Variables
  long wait_mS
  long elapsedtime
  long slow_loop_count
  long medium_loop_count
  long fast_loop_count
  byte prioritylevel
  word ontime
  long armedtimer
  byte armedstart

  'UART Variables
  long stack[10]  
  byte rxbyte,rxinit  
  byte tempbyte
  byte tempstr1[50]
  byte  stringbuffer[100]
  byte comrxbuffer[100] 
  

  'Motor Variables
  byte Armed

  'Obstacle Detection/Avoidance Variables
  long front_distance
  long left_distance
  long right_distance
  long occupancy_grid[GRIDSIZE*GRIDSIZE]
  long com_x
  long com_y
  long target_x
  long target_y
  long target_theta
  long target_speed
  
  'SD Card Variables
  byte tbuf[20]
  byte bigbuf[256]
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

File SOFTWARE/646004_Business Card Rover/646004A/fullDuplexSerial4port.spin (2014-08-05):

{{  FullDuplexSerial4portPlus version 1.01
  - Tracy Allen (TTA)   (c)22-Jan-2011   MIT license, see end of file for terms of use.  Extends existing terms of use.
  - Can open up to 4 independent serial ports, using only one pasm cog for all 4.
  - Supports flow control and open and inverted baud modes
  - Individually configurable tx and rx buffers for all 4 ports, any size, set in CONstants section at compile time
  - Part of the buffer fits within the object's hub footprint, but even so the object is restartable
  - Buffers are DAT type variables, therefore a single instance of the object can be accessed throughout a complex project.

  - Modified from Tim Moore's pcFullDuplexSerial4fc, with further motivation and ideas from Duane Degn's pcFullDuplexSerial4fc128
  - Changes and bug fixes include:
    - Flow control is now operational when called for, with correct polarity (bug correction)
    - Jitter is reduced, unused ports are properly skipped over (bug correction), operation speed is increased.
    - Stop bit on reception is now checked, and if there is a framing error, the byte is not put in the buffer.
    - Buffer sizes are arbitrary, each port separate rx & tx up to available memory
       Changes in pasm and in Spin methods to accomodate larger buffers, major reorganization of DAT section.
    - Added strn method for counted string, and rxHowFull method for buffer size.
    - Cut out most of the format methods such as DEC and HEX, expecting those to be their own object calling rx, tx, str and strn methods.
      See companion object DataIO4port.spin in order to maintain compatibility with methods in the original pcFullDuplexSerial4fc.

  - 1v01
    - init method returns pointer @rxsize, for data buffers and data structure.
  - 1v00
    - documentation
  - 0v91
    - restored DEFAULTTHRESHOLD constant
    - made default buffer sizes in the DAT section rather than init
    - removed the numeric methods to their own companion object, dataIO4port.
  - 0v3
    - first public release with the jitter and flow control issues fixed, and large buffers.

  Links:
  Development of this version:
  --- http://forums.parallax.com/showthread.php?137349-yet-another-variant-fullDuplexSerial4portplus
  Tim Moore's original pcFullDuplexSerial4fc and updates to allow flow control:
  --- http://forums.parallaxinc.com/forums/default.aspx?f=25&p=1&m=273291#m276667
  --- http://obex.parallax.com/objects/340/      7/24/08 version
  --- http://forums.parallaxinc.com/forums/default.aspx?f=25&p=1&m=349173    8/14/08 update, flow polarity correction, not in obex
  Duane Degn's thread, larger 128 or 512 byte buffers and reusing buffer space, discussion of issues
  --- http://forums.parallax.com/showthread.php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
  Juergen Buchmueller, 2 port trimmed down version
  --- http://forums.parallax.com/showthread.php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
  Serial Mirror, single port but same idea regarding buffers in the DATa space
  --- http://forums.parallax.com/showthread.php?94311-SerialMirror-A-FullDuplexSerial-enhancement
  --- http://obex.parallax.com/objects/189/
  Re baud rates attainable, hiccups:
  --- http://forums.parallaxinc.com/forums/default.aspx?f=25&p=1&m=282923#m282978
  --- http://forums.parallaxinc.com/forums/default.aspx?f=25&p=1&m=334784
  --- http://forums.parallax.com/showthread.php?120868-FullDuplexSerial-hiccups
  Jitter, discussions of jitter in different Prop serial programs, PhiPi's development of PBnJ full duplex:
  --- http://forums.parallax.com/showthread.php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
  --- http://forums.parallax.com/showthread.php?136431-Serial-objects-question
  Humanoido's catalog of serial port objects
  --- http://forums.parallax.com/showthread.php?128184-Serial-Objects-for-SPIN-Programming
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

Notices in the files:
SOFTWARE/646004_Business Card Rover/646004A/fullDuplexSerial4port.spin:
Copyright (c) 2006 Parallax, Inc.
